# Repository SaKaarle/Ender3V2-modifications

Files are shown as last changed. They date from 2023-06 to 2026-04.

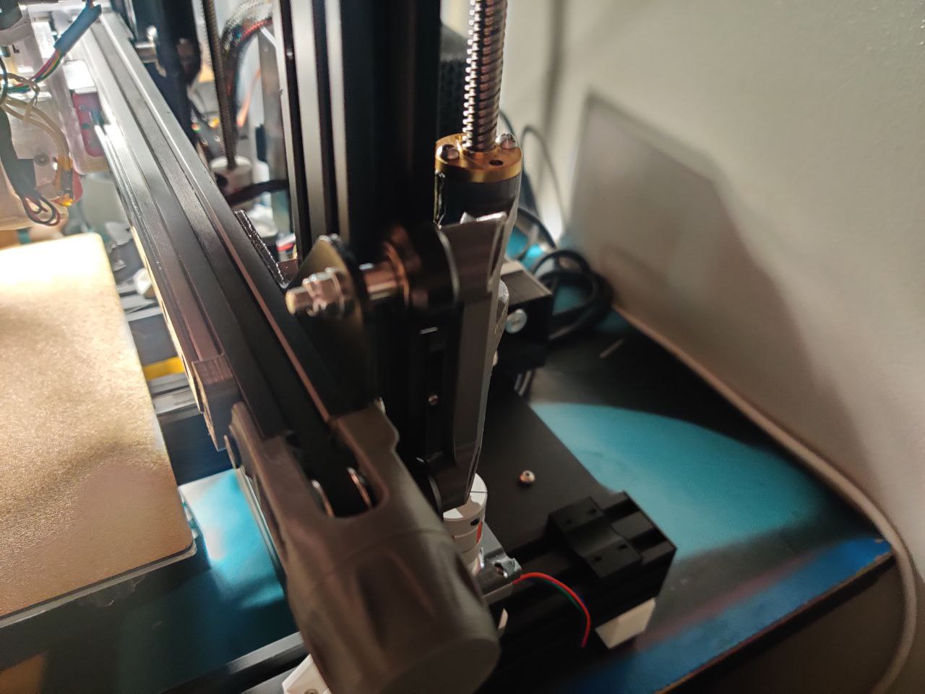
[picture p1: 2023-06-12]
pictures/photo1686598149(1).jpeg

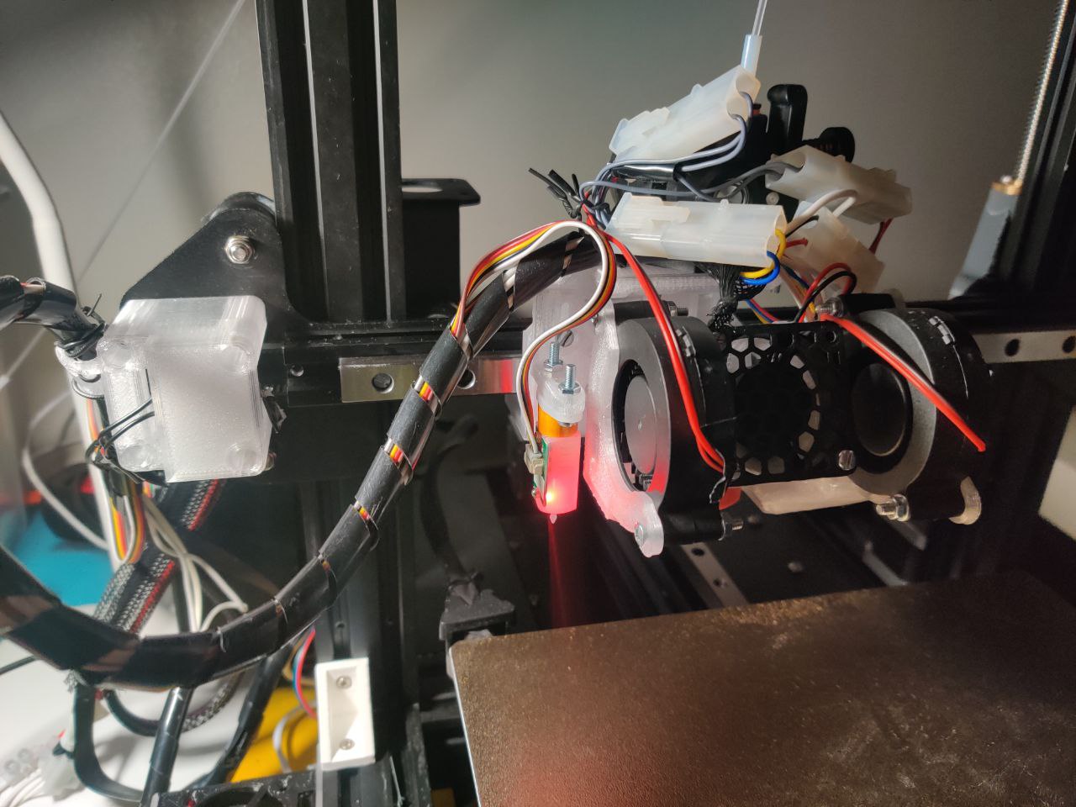
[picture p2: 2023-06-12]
pictures/photo1686598149(3).jpeg

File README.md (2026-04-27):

# Ender3V2-modifications
Mods of my Ender 3 V2 with .blend and .STL files
Also information.
  
## List:
- [What have I done](#what-else-what-have-i-done)
- [Required modding](#required-modding)
- [Filament spool / roll weights](#filament-spool--roll-weights)

## Backing up .blend files
This repo is made for me to publicly upload my mods and methods I used for creating my own modifications.
## Why and what?
Personal backup, and helping myself to remember what tools I used and what I have done to make my ENDER 3V2 personal without any CAD background.
I'm trying to be crystal clear, open and link any of my mods that I remixed or modified. Not trying to break any rules as great as possible.

## Blender? Really? NO PLEASE NO
### FreeCAD > Blender
  
Blender is good for simple mesh edits / remixes, but still. Wasting time on blender CAD Sketcher is not a good idea.
## What else? What have I done?

List of mods that are edited to my flavour.
- X-axis cover (Destroyed my M3 x 40mm screws. Had to create M3 x 30mm screw mod. Then I added limit switch mod for Linear Mod carriage)
- X-axis linear rail carriage.
- Dual Z-axis to fit washers and better support for Z-axis motor. Coupler was hitting the original part.
- Y-axis motor holder. Was hitting bed tensioner screws. It needs to be modded / replaced.
- Y-axis drilling helpper. Holes for MGN12 linear rail. It needs changes and I have to create mod that supports Y-axis belt better and make it more straight.
  
These are just top of my head what I remember, but I'll create better list of parts and mods.

## Required Modding
  
**X-axis:** It has had SOME mods and fixes. BLV set with [FrankEnstein](https://github.com/kevinakasam/FrankEnstein-Duct/tree/main) and modded base to fit screws and hold it together better on the X gantry / carriage.
X-axis only needs Motor holder / endswitch holder which would be better and for double shear support. Not necessary this last part but better than nothing.
  
**Y-axis:** Uses BLV base, but could use dual mgn rail system. Not sure if it's benefitting at all for acceleration results, but will see. Currently max y-axis acceleration is 5000, but I use 10000mm/s². Seams will show the high acceleration results.
Y-axis upgrade path is simple: Dual MGN rail. New bed heater system. New bed heater means = New PSU and silicon heater.
  
**Z-axis:** Dual leadscrew / BLV Z-axis. I could just use KevinAkaSam's Z-axis mod. Only needs printing the necessary parts.
Z-axis not necessarily needs upgrade, except the belted mod. 
  
**DUCT:** Yeah nothing really. FrankEnstein V2
  
**Extruder:** Orbiter V2.0 -> V2.5 upgrade done. Better quality? "yes". Worth it? I guess?
  
**Enclosure:** Needs filtering system
  
**Motherboard and Electronics:** GPIO pins, fans and new motherboard holder location and design. Led control from RPi 5 or from RPi Pico.
  
**Filament runout sensor:** Not installed

## Filament spool / roll weights
  
- CR-PETG or maybe other Creality Plastic roll weight: **190g**
- Fuj:tech Cardboard filament roll weight: **220g**
- Sunlu JAYO, old mass producted filament roll weight: **133g**

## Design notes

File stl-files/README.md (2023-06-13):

# STL files of mods

`rinkula.stl` file is for Y stopper switch to activate. Some moveable printable Y switch holder is fine and works. Literally made 2-3 wheels to act as "replacement" for POM Wheels that hit the Y switch.

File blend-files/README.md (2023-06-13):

# Backup of files
## Main Duct mod
[Main duct mod is huge. 100mb and it's like test enviroment](https://github.com/SaKaarle/Ender3V2-modifications/blob/main/blend-files/ModdedVersionDuct.7z)
It has my old mods, tests etc. Didn't cleaned it.

It also contains the X-axis carriage mod for linear rails. It's remixed to have:
- thicker bottom for strenght. needs changes for belts. Straightening the belt by adding height piece before the holes. Easier way i'd guess. If I really wanted to strenght to that piece, I'd add 3 long M3 - M4 to press on belts.
- added 2 nut holes for BLTouch. Prolly going to change it due to the center screwhole is behind left side fanduct.
- leftside stopper for better switch action. Original didn't hit well on the switch so I added more contact area
- 2 holes that are unnecessary. Should be removed.
- Hotend screwholes. Originals were "odd" shaped and I changed them to cylinderlike shape. This gives me chance to change from my Hero Me Gen -mod to Frankenstein-Duct easly for example.

## Duct With No Name
It's Minimev4 or minionD mod fused with hero me gen. HMG has great ducts IMO and I added a support for it. It can be printed without BMS Dragonfly adapter to support MK8 style hotend.
It has little cable management for Thermistor and heater cable.

No heatinsert? no. I mod and print a lot so obviously it would've been waste of brass. 

It's integrated with Orbiter V2.0 extruder and added small flex support. 2 holes for zipties for cable

Modular BLTouch support that needs changes

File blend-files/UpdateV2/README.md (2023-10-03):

Updated version:
Changes:
- Made changes to fanduct. Created "own" fan holes and lowered Orbiter extruder mount about 8mm downwards.
- Stronger (but flexing still on PET-G materials, not a surprise)
- Moved extruder holes 1mm towards front
- ADXL345 mount (not tested)
- BLTouch mount changes. Got annoying to change fans or what not. Made it more "easy" to access / mod. Not tested if it even fits or measured distance between BLTouch and nozzle.

Issues:
- Not tested
- Fan performance not tested. Model needs somekind of "duct" towards hotend.

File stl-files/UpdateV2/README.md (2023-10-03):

Updated STL files and blend files.

Performance? Unknown.

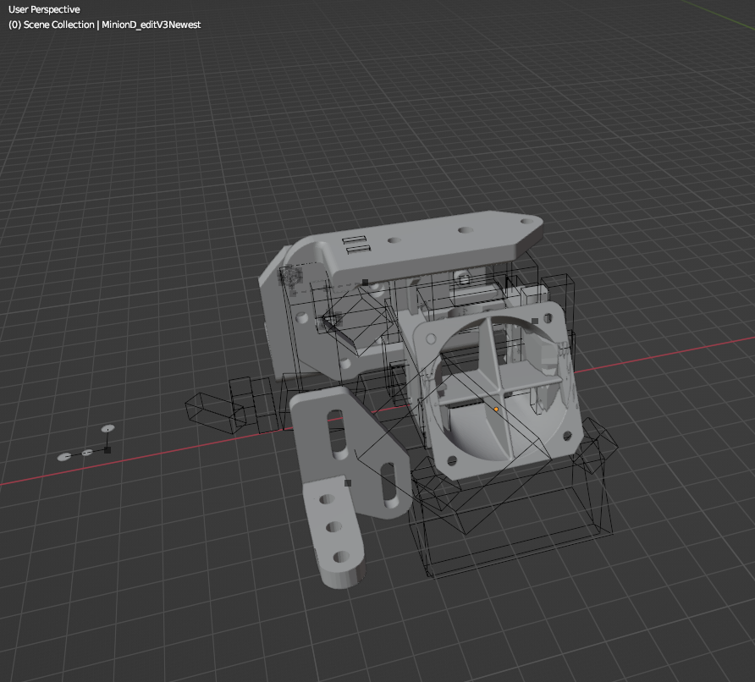
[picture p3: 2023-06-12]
pictures/GitHub ugly mod.PNG

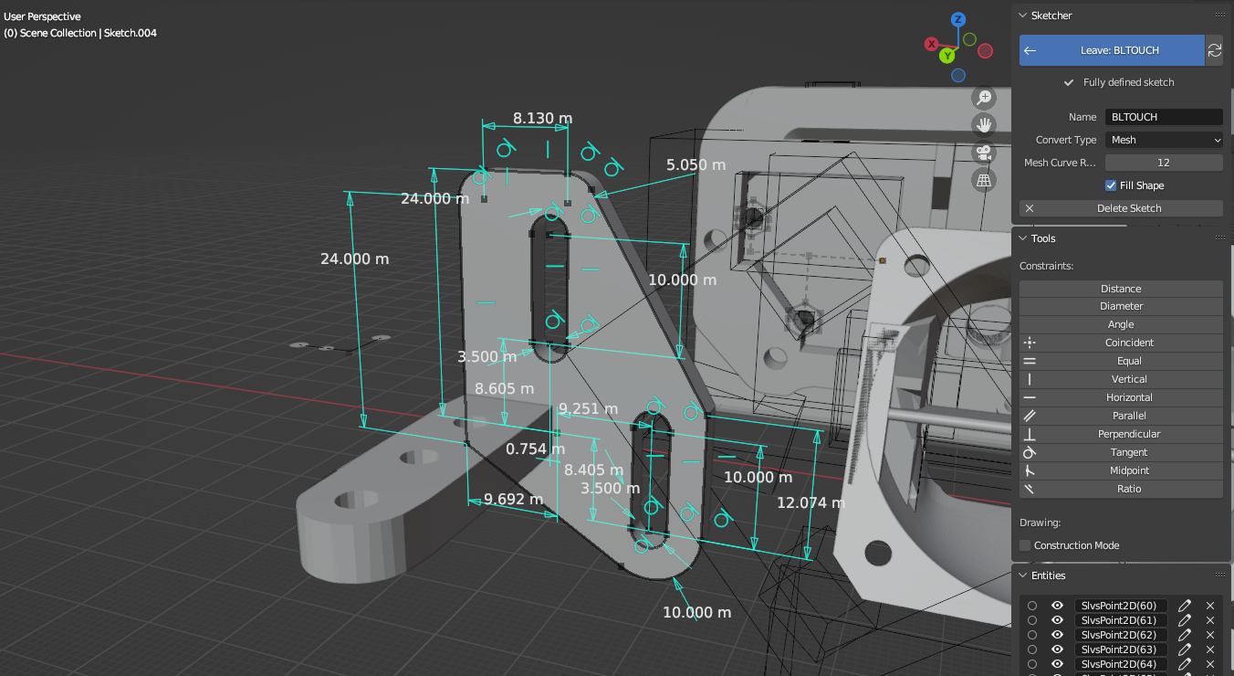
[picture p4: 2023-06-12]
pictures/GitHub_BLtouch.PNG

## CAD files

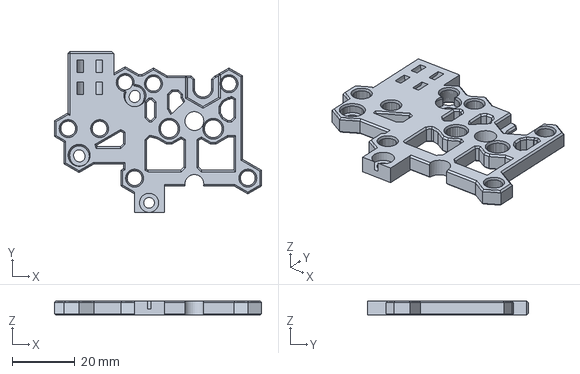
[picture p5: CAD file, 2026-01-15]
Mods/BasePlateEdit.FCStd
65.8 x 51.0 x 4.50 mm

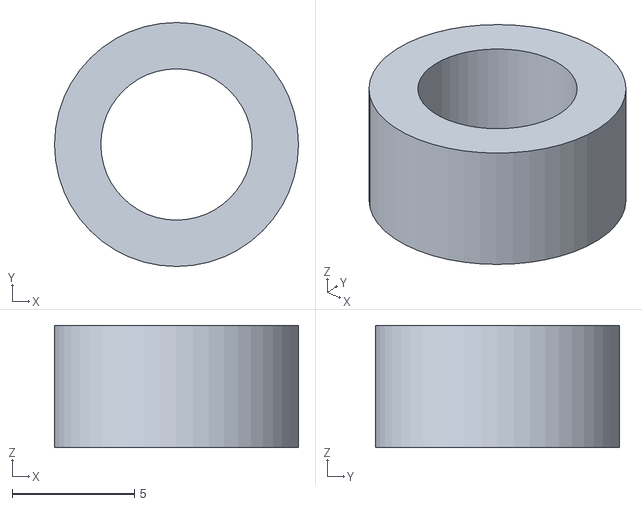
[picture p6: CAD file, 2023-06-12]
stl-files/BED Linear Mod Ender 3 v2-Rinkula.stl
10.0 x 10.0 x 5.00

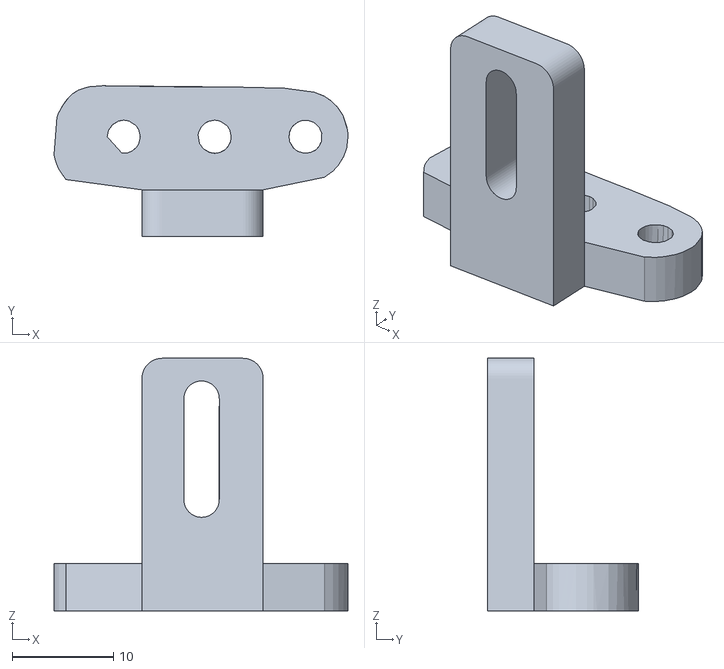
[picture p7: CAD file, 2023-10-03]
stl-files/UpdateV2/ModdedVersionDuct-BLTOUCH2.stl
29.1 x 14.9 x 25.0

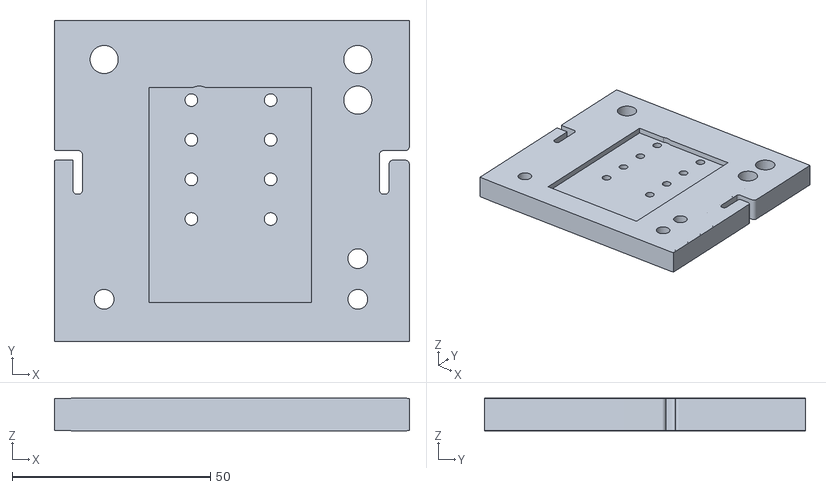
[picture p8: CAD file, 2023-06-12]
stl-files/BED Linear Mod Ender 3 v2-BED_Linear_Mod_Ender_3_v2-Creality-Ender3-V2-rev4_002.stl
89.6 x 81.0 x 8.20

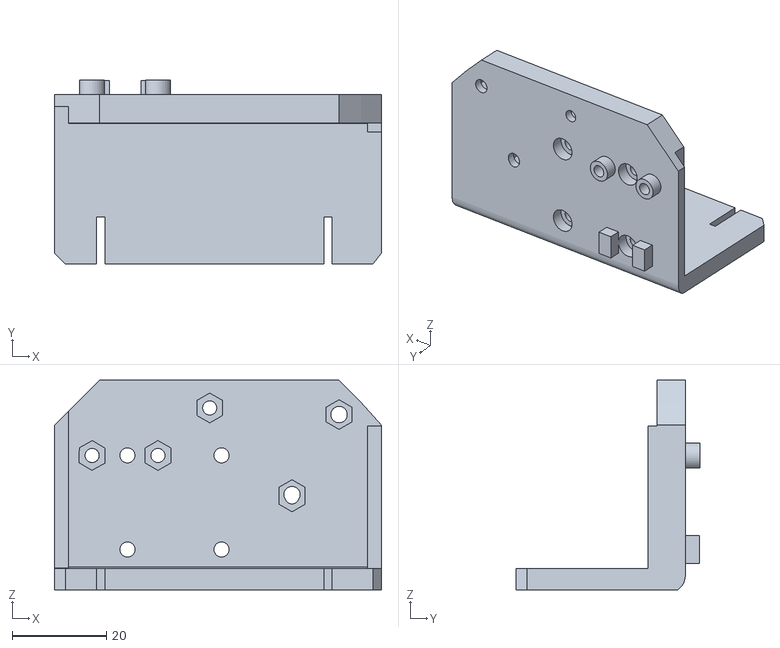
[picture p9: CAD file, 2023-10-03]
stl-files/UpdateV2/ModdedVersionDuct-Linear_rail_MGN12_x_axis_backplate_modded_V2.stl
69.5 x 39.1 x 44.6

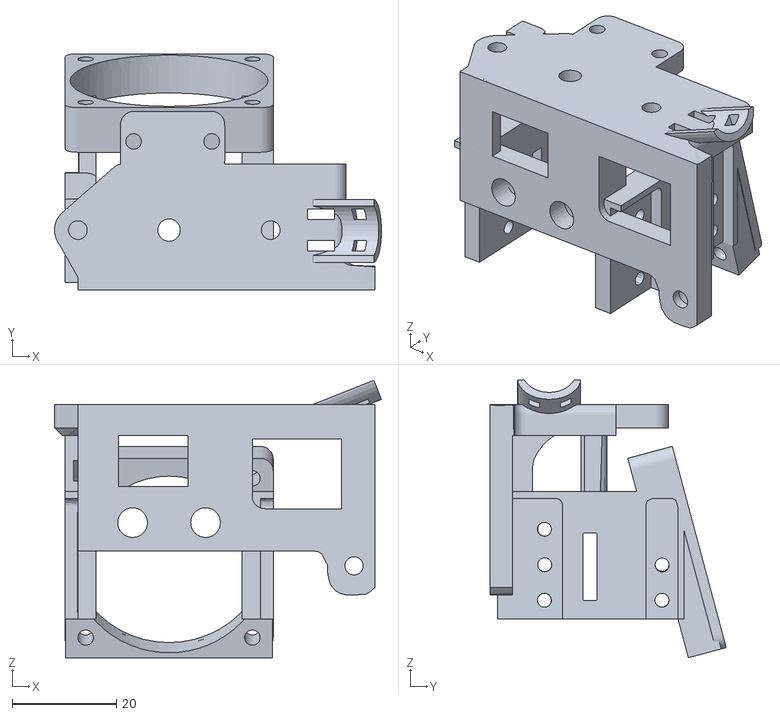
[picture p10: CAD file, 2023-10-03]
stl-files/UpdateV2/ModdedVersionDuct-FANShroud_003.stl
62.8 x 45.4 x 53.3

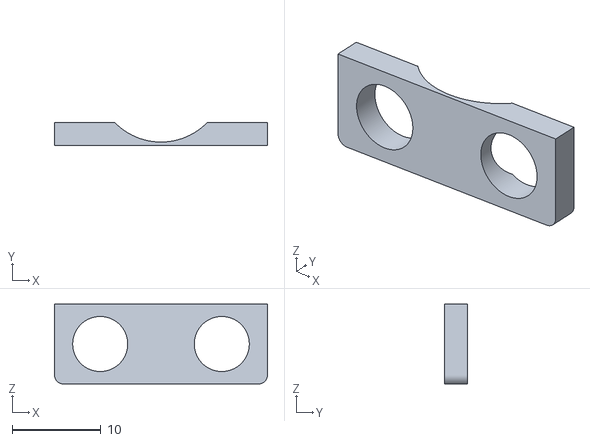
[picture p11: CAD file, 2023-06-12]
stl-files/ModdedVersionDuct-Dragon_Fly_Phaetus_Spacer_modded.stl
24.0 x 2.59 x 9.00

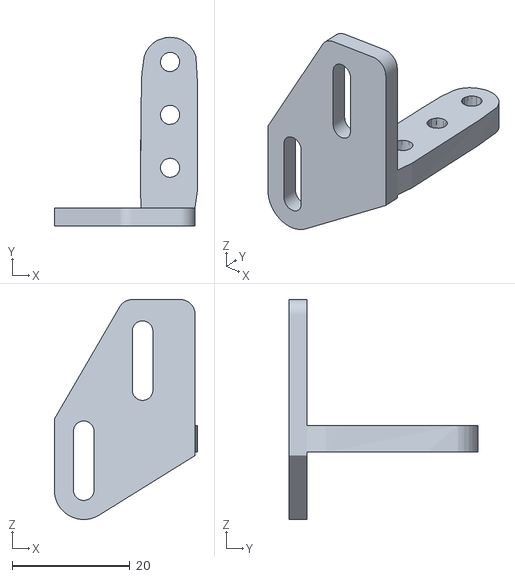
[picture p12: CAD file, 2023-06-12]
stl-files/ModdedVersionDuct-BLTOUCH.stl
24.4 x 32.1 x 37.4

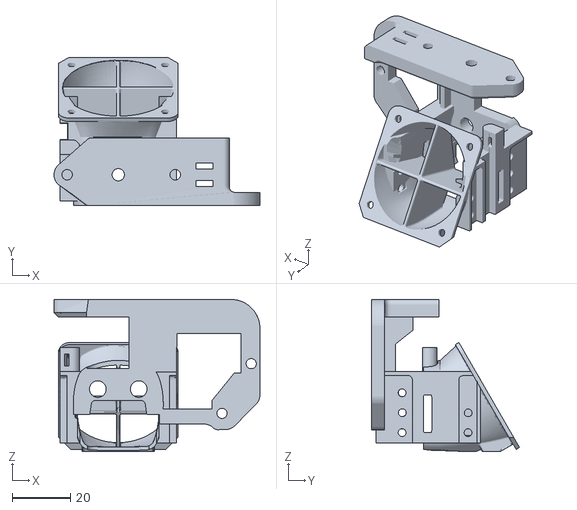
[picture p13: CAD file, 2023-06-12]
stl-files/ModdedVersionDuct-MinionD_editV3Newest.stl
70.5 x 50.7 x 52.1

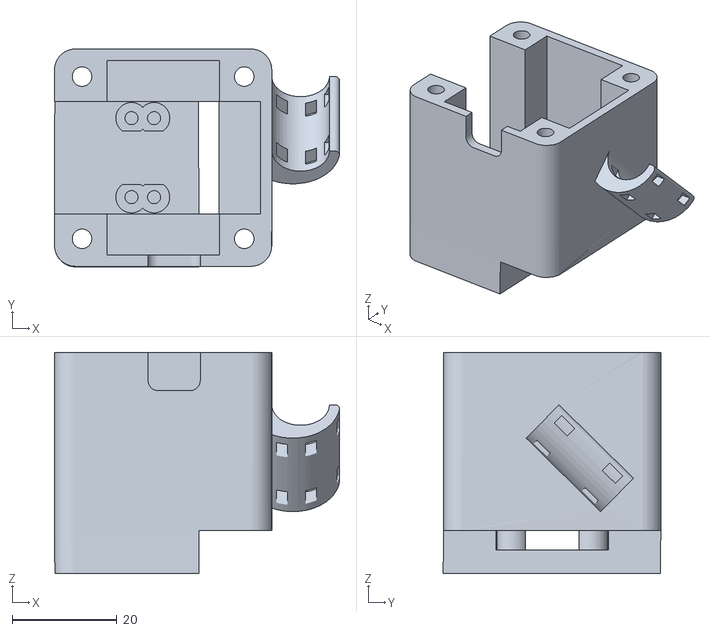
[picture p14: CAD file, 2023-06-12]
stl-files/X_AXIS_EDIT_m3x30mm_screws-x_axis_cover_cable_003.stl
54.5 x 41.6 x 42.3

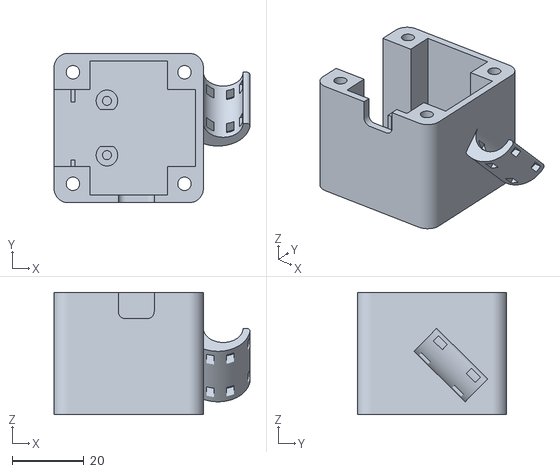
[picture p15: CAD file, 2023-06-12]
stl-files/X_AXIS_EDIT_m3x30mm_screws-x_axis_cover_cable_NonLinearRail.stl
54.5 x 41.5 x 34.0

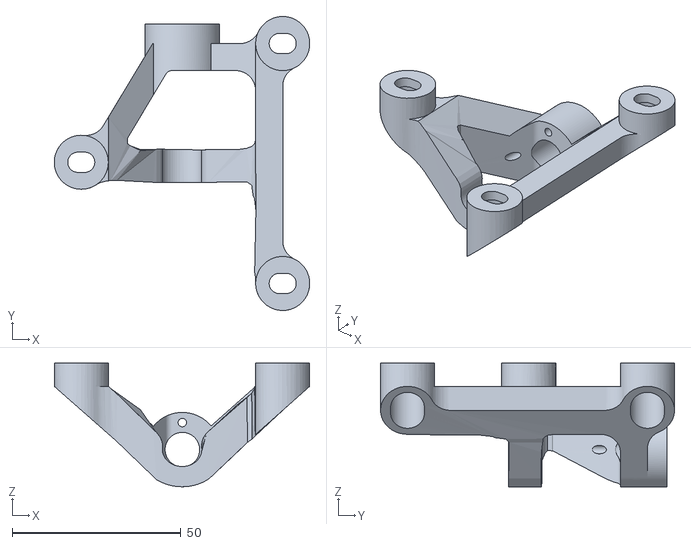
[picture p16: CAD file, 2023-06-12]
stl-files/ZaxisFix-Bracket_without_insertsSpaceWashers0_9mm_001.stl
75.6 x 87.0 x 36.6

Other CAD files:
Mods/BasePlateEdit-BodyHoleFinishedIguess.3mf
stl-files/ModdedVersionDuct-Linear_rail_MGN12_x_axis_backplate_modded_V3.stl
stl-files/ZaxisFix-Bracket_without_insertsSpaceWashers0_9mm.stl
blend-files/80mmSlimEdit.blend
blend-files/BED Linear Mod Ender 3 v2.blend
blend-files/BEDModel.blend
blend-files/BalikkaSpool.blend
blend-files/OrbiterEdit_v1.blend
blend-files/SpoolHolder V2.blend
blend-files/X_AXIS_EDIT_m3x30mm_screws.blend
blend-files/Y-axis Edit.blend
blend-files/ZaxisFix.blend
blend-files/ZaxisFix_V2.blend

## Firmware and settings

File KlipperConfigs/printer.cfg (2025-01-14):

# This file contains common pin mappings for the BIGTREETECH SKR mini
# E3 v3.0. To use this config, the firmware should be compiled for the
# STM32G0B1 with a "8KiB bootloader" and USB communication/USART.

# usb-Klipper_stm32g0b1xx_1300350015504B5735313920-if00


# The "make flash" command does not work on the SKR mini E3. Instead,
# after running "make", copy the generated "out/klipper.bin" file to a
# file named "firmware.bin" on an SD card and then restart the SKR
# mini E3 with that SD card.

# See docs/Config_Reference.md for a description of parameters.

### Calibrations:
# Flow Rate / Extrusion Multiplier
# 89 - 91
# 90.5 def
# 0.965 best?

# Cura Start End G-Codes
# START_PRINT BED_TEMP={material_bed_temperature_layer_0} EXTRUDER_TEMP={material_print_temperature_layer_0}
# END_PRINT

# https://www.klipper3d.org/G-Codes.html#print_stats

# Orca
# start_print BED_TEMP=[bed_temperature_initial_layer_single] EXTRUDER_TEMP=[nozzle_temperature_initial_layer]

### Important notes:
### - Hero Me Gen Fan Speed Max 75% PLA
### - 

## Client variable macro for your printer.cfg
[gcode_macro _CLIENT_VARIABLE]
variable_use_custom_pos   : True ; use custom park coordinates for x,y [True/False]
variable_custom_park_x    : 10.0   ; custom x position; value must be within your defined min and max of X
variable_custom_park_y    : 10.0   ; custom y position; value must be within your defined min and max of Y
variable_custom_park_dz   : 2.0   ; custom dz value; the value in mm to lift the nozzle when move to park position
variable_retract          : 1.0   ; the value to retract while PAUSE
variable_cancel_retract   : 5.0   ; the value to retract while CANCEL_PRINT
variable_speed_retract    : 35.0  ; retract speed in mm/s
variable_unretract        : 1.0   ; the value to unretract while RESUME
variable_speed_unretract  : 35.0  ; unretract speed in mm/s
variable_speed_hop        : 30.0  ; z move speed in mm/s
variable_speed_move       : 100.0 ; move speed in mm/s
variable_park_at_cancel   : True ; allow to move the toolhead to park while execute CANCEL_PRINT [True/False]
variable_park_at_cancel_x : 245.0  ; different park position during CANCEL_PRINT [None/Position as Float]; park_at_cancel must be True
variable_park_at_cancel_y : 234.0  ; different park position during CANCEL_PRINT [None/Position as Float]; park_at_cancel must be True
# !!! Caution [firmware_retraction] must be defined in the printer.cfg if you set use_fw_retract: True !!!
variable_use_fw_retract   : False ; use fw_retraction instead of the manual version [True/False]
variable_idle_timeout     : 0     ; time in sec until idle_timeout kicks in. Value 0 means that no value will be set or restored
gcode:


## includes:
[include mainsail.cfg]
[include fluidd.cfg]
[include KAMP_Settings.cfg]
#[include Adaptive_Mesh.cfg]
#[include Line_Purge.cfg]
[include Input_Shaper.cfg]
[include StepperConf.cfg]

[extruder]
max_extrude_only_distance: 500.0
max_extrude_only_velocity: 120.0
max_extrude_cross_section: 5
max_extrude_only_accel: 6000
step_pin: PB3
# != negative dir
dir_pin: PB4
enable_pin: !PD1
microsteps: 16 #128
full_steps_per_rotation: 200
rotation_distance: 4.586 #4.609 vakio: 4.637
nozzle_diameter: 0.400
filament_diameter: 1.750
pressure_advance: 0.04
pressure_advance_smooth_time: 0.03

# 110 + || - measured_value = length
# length / 100 * old_rotation_distance = new rotation distance
# 110 - 11 = 99 -> 99/100 = 0.99 -> 0.99 * 4,587 = 4.54113
# 26.11.2023 = 4.65
# 4.666
# 4.625
# 4,666 * 99,12 / 100


heater_pin: PC8
sensor_type: EPCOS 100K B57560G104F
sensor_pin: PA0
min_temp: 0
max_temp: 300
min_extrude_temp: 170

[tmc2209 extruder]
uart_pin: PC11
tx_pin: PC10
uart_address: 3
interpolate: true
# stealthchop_threshold: 0
run_current: 0.83 #** 0.85 max RMS amp. Good value 0.75
# hold_current: 0.100
sense_resistor: 0.11 #**
driver_TBL: 0
driver_HEND: 6
driver_HSTRT: 7
driver_TOFF: 4

[printer]
kinematics: cartesian
max_velocity: 400
max_accel: 10000
# 50mm^2  +  2 × 10000 mm/s2 × (0.5 ratio × 100mm) = 1002500 mm/s??? end_velocity^2
minimum_cruise_ratio: 0.5
#max_accel_to_decel: 5000 # <- #max_accel_to_decel:
#   A pseudo acceleration (in mm/s^2) controlling how fast the
#   toolhead may go from acceleration to deceleration. It is used to
#   reduce the top speed of short zig-zag moves (and thus reduce
#   printer vibration from these moves). The default is half of
#   max_accel.
square_corner_velocity: 5.0
max_z_velocity: 30 #15
max_z_accel: 500

[stepper_x]
step_pin: PB13
dir_pin: !PB12
enable_pin: !PB14
microsteps: 32 #128 tai 32 no interp
rotation_distance: 40
endstop_pin: ^PC0
position_endstop: -1
position_min: -1
position_max: 248
homing_speed: 80

[tmc2209 stepper_x]
uart_pin: PC11
tx_pin: PC10
uart_address: 0
run_current: 1.03
interpolate: False #False
stealthchop_threshold: 0

[stepper_y]
step_pin: PB10
dir_pin: PB2 # 48motor had "!PB2". 60mm has non. 
enable_pin: !PB11
microsteps: 32 #128 tai 32 no interp
rotation_distance: 40
endstop_pin: ^PC1
#-12
position_endstop: -15
#-12
position_min: -15
position_max: 237
homing_speed: 80

[tmc2209 stepper_y]
uart_pin: PC11
tx_pin: PC10
uart_address: 2
run_current: 0.98 #Old 0.96. 1.03 vois olla liian kuuma. 1.4 laskemalla...
interpolate: False #False
stealthchop_threshold: 0

[stepper_z]
step_pin: PB0
dir_pin: PC5
enable_pin: !PB1
microsteps: 32 #128
rotation_distance: 8
# endstop_pin: ^PC2
# position_endstop: 0.0
endstop_pin: probe:z_virtual_endstop
position_min: -5
position_max: 250

[tmc2209 stepper_z]
uart_pin: PC11
tx_pin: PC10
uart_address: 1
run_current: 1.05 #1.6 or 1.58. Dual Z axis motors.
interpolate: False #False
stealthchop_threshold: 0


[heater_bed]
heater_pin: PC9
sensor_type: EPCOS 100K B57560G104F
sensor_pin: PC4
min_temp: 0
max_temp: 130

[heater_fan hotend_fan]
pin: PB15
heater: extruder
heater_temp: 45.0
fan_speed: 0.97
#   The fan speed (expressed as a value from 0.0 to 1.0) that the fan
#   will be set to when its associated heater is enabled. The default
#   is 1.0

[controller_fan electronic_enclosure_fan]
pin: PC7
idle_timeout: 60

[fan]
pin: PC6

[mcu]
serial: /dev/serial/by-id/usb-Klipper_stm32g0b1xx_1300350015504B5735313920-if00
# serial: /dev/ttyAMA0
# restart_method: command

[board_pins]
aliases:
    # EXP1 header
    EXP1_1=PB5,  EXP1_3=PA9,   EXP1_5=PA10, EXP1_7=PB8, EXP1_9=<GND>,
    EXP1_2=PA15, EXP1_4=<RST>, EXP1_6=PB9,  EXP1_8=PD6, EXP1_10=<5V>

[mcu rpi]
serial: /tmp/klipper_host_mcu

[adxl345]
cs_pin: rpi:None

[resonance_tester]
accel_chip: adxl345
probe_points:
    117.5, 117.5, 30  # an example

[bltouch]
sensor_pin: ^PC14
control_pin: PA1
##Oma modi BLTouch = 43.8 - 4.5 = 39.3
## 10.2 - 9.81 = 0.39
x_offset: -52.0 #50
y_offset: -3.0 #5
#z_offset = 1.625
#z_offset: -1.225

#[output_pin beeper]
#pin: PB5

[safe_z_home]
home_xy_position:169.5,120.5
# Change coordinates to the center of your print bed

z_hop:7
z_hop_speed:30
speed:300
# Move up 10mm z_hop_speed: 5


[bed_mesh]

##Laskettu arvo 0,0 -> 39.15,39.15 -> ProbePoint 0,0 -> 78.4,39.15 -> 0,1 -> 156.6,39.15 -> 0,2
## X = (bltouch_x)43.8 + (bed_point_y)39.15 = 82.95
## Y = (bltouch_y)10.2 + (bed_point_y)39.15 = 49.35
## 195.75

speed:300
horizontal_move_z:7
mesh_min:47.5,47.5
mesh_max:188.5,188.5
probe_count:5,5
algorithm:lagrange
fade_start:1
fade_end:10
fade_target:0

[gcode_macro probe_calibration]
gcode: PROBE_CALIBRATE

[gcode_macro screws_tilt_adjust]
gcode: SCREWS_TILT_CALCULATE

[screws_tilt_adjust]
## 35 + 43.8
## 35 + 10.2
## 235 - 43.8
## 235 - 10.2
screw1:102,53
screw1_name:front left screw
screw2:237,53
screw2_name:front right screw
screw3:237,188
screw3_name: rear right screw
screw4:102,188
screw4_name: rear left screw
horizontal_move_z: 10
speed: 300
screw_thread: CW-M4

# screw1:70.5,37.5
# screw1_name:front left screw
# screw2:225,37.5
# screw2_name:front right screw
# screw3:225,207.5
# screw3_name: rear right screw
# screw4: 70.5,207.5
# screw4_name: rear left screw
# horizontal_move_z: 10
# speed: 50
# screw_thread: CW-M4

#====================================================================

# TEMPERATUR SENSORS

#====================================================================

[temperature_sensor rpi_temp]
sensor_type: temperature_host
sensor_path: /sys/class/thermal/thermal_zone0/temp
#   The path to temperature system file. The default is
#   "/sys/class/thermal/thermal_zone0/temp" which is the temperature
#   system file on a Raspberry Pi computer.

[temperature_sensor raspberry_pi]

sensor_type: temperature_host
min_temp: 10
max_temp: 100

[temperature_sensor Board Temp]

sensor_type: temperature_mcu
min_temp: 0
max_temp: 100

[virtual_sdcard]
path: /home/pi/printer_data/gcodes

# Enable object exclusion
[exclude_object]
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

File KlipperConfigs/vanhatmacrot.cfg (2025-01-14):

[gcode_macro START_PRINT]
gcode:
    {% set BED_TEMP = params.BED_TEMP|default(60)|float %}
    {% set EXTRUDER_TEMP = params.EXTRUDER_TEMP|default(190)|float %}
    # Start bed heating
    M140 S{BED_TEMP}
    # Use absolute coordinates
    G90
    # Reset the G-Code Z offset (adjust Z offset if needed)
    SET_GCODE_OFFSET Z=0.0
    # Home the printer
    G28
    #BED_MESH_CALIBRATE
    G29
    #BED_MESH_PROFILE LOAD=default

    G1 Z5 F3000
    # Move the nozzle very close to the bed
    # ??????????????????? G1 Z0.15 F300
    # Wait for bed to reach temperature
    M190 S{BED_TEMP}
    # Set and wait for nozzle to reach temperature
    M109 S{EXTRUDER_TEMP}
    #RESPOND MSG="Yeet"

    G1 Y0 ; 
    LINE_PURGE ; purge macro

    # Reset Extruder
    # G92 E0
    # # Move Z Axis up
    # G1 Z2.0 F3000
    # # Move to start position
    # G1 X2.1 Y20 Z0.28 F5000.0
    # # Draw the first line
    # G1 X2.1 Y200.0 Z0.28 F1500.0 E15
    # # Move to side a little
    # G1 X2.4 Y200.0 Z0.28 F5000.0
    # # Draw the second line
    # G1 X2.4 Y20 Z0.28 F1500.0 E30
    # # Reset Extruder
    # G92 E0
    # # Move Z Axis up
    # G1 Z2.0 F3000

# gcode:
#     G28
#     BED_MESH_CALIBRATE
#     G0 X0 Y0 Z10 F6000
#     BED_MESH_PROFILE save=default
#     SAVE_CONFIG
#[gcode_macro G28]
#gcode: home

#region old macros

# [gcode_macro PAUSE]
# description: Pause the actual running print
# rename_existing: PAUSE_BASE
# # change this if you need more or less extrusion
# variable_extrude: 1.0
# gcode:
#   ##### read E from pause macro #####
#   {% set E = printer["gcode_macro PAUSE"].extrude|float %}
#   ##### set park positon for x and y #####
#   # default is your max posion from your printer.cfg
#   {% set x_park = printer.toolhead.axis_maximum.x|float - 5.0 %}
#   {% set y_park = printer.toolhead.axis_maximum.y|float - 15.0 %}
#   ##### calculate save lift position #####
#   {% set max_z = printer.toolhead.axis_maximum.z|float %}
#   {% set act_z = printer.toolhead.position.z|float %}
#   {% if act_z < (max_z - 2.0) %}
#       {% set z_safe = 2.0 %}
#   {% else %}
#       {% set z_safe = max_z - act_z %}
#   {% endif %}
#   ##### end of definitions #####
#   PAUSE_BASE
#   G91
#   {% if printer.extruder.can_extrude|lower == 'true' %}
#     G1 E-{E} F2100
#   {% else %}
#     {action_respond_info("Extruder not hot enough")}
#   {% endif %}
#   {% if "xyz" in printer.toolhead.homed_axes %}
#     G1 Z{z_safe} F900
#     G90
#     G1 X{x_park} Y{y_park} F6000
#   {% else %}
#     {action_respond_info("Printer not homed")}
#   {% endif %} 
#========================================
#OMA VANHA START PRINT
#========================================

# [gcode_macro START_PRINT]
# gcode:
#     {% set BED_TEMP = params.BED_TEMP|default(60)|float %}
#     {% set EXTRUDER_TEMP = params.EXTRUDER_TEMP|default(190)|float %}
#     # Start bed heating
#     M140 S{BED_TEMP}
#     # Use absolute coordinates
#     G90
#     # Reset the G-Code Z offset (adjust Z offset if needed)
#     SET_GCODE_OFFSET Z=0.0
#     # Home the printer
#     G28
#     #BED_MESH_CALIBRATE
#     G29
#     #BED_MESH_PROFILE LOAD=default
    
#     # Move the nozzle near the bed
#     G1 Z5 F3000
#     # Move the nozzle very close to the bed
#     G1 Z0.15 F300
#     # Wait for bed to reach temperature
#     M190 S{BED_TEMP}
#     BED_MESH_PROFILE LOAD=default
    
#     # Set and wait for nozzle to reach temperature
#     M109 S{EXTRUDER_TEMP}

#     #G1 Z2.0 F3000 ; Move Z Axis up little to prevent scratching of Heat Bed
#     G1 X0.1 Y20 Z0.3 F5000.0 ; Move to start position
#     G1 X0.1 Y200.0 Z0.3 F1500.0 E15 ; Draw the first line
#     G1 X0.4 Y200.0 Z0.3 F5000.0 ; Move to side a little
#     G1 X0.4 Y20 Z0.3 F1500.0 E30 ; Draw the second line
#     G92 E0 ; Reset Extruder
#     G1 Z2.0 F3000 ; Move Z Axis up little to prevent scratching of Heat Bed
#     G1 X5 Y20 Z0.3 F5000.0 ; Move over to prevent blob squish
    
#     # # Move to start for purge line
#     # G1 X0.1 Y20 Z0.3 F5000.0
#     # # Draw 1st line
#     # G1 X0.1 Y150.0 Z0.3 F1500.0 E15
#     # # Move to side a little
#     # G1 X0.4 Y150.0 Z0.3 F5000.0
#     # # Draw 2nd line
#     # G1 X0.4 Y20 Z0.3 F1500.0 E30
#     # # Reset extruder
#     # G92 E0
#     # # Move Z up a little
#     # G1 Z5.0 F3000

#=========================================================
#Vanha End Print
#=========================================================

# [gcode_macro END_PRINT]
# gcode:
#     # # Turn off bed, extruder, and fan
#     # M140 S0
#     # M104 S0
#     # M106 S0
#     # # Move nozzle away from print while retracting
#     # G91
#     # G1 X-2 Y-2 E-3 F300
#     # # Raise nozzle by 10mm
#     # G1 Z10 F3000
#     # G90
#     # # Disable steppers
#     # M84

#     G91 ;Relative positioning
#     G1 E-2 F2700 ;Retract a bit
#     G1 E-2 Z0.2 F2400 ;Retract and raise Z
#     G1 X5 Y5 F3000 ;Wipe out
#     G1 Z10 ;Raise Z more
#     G90 ;Absolute positioning

#     #G1 X0 Y{machine_depth} ;Present print
#     M106 S0 ;Turn-off fan
#     M104 S0 ;Turn-off hotend
#     M140 S0 ;Turn-off bed

#     M84 X Y E ;Disable all steppers but Z

# [gcode_macro RESUME]
# description: Resume the actual running print
# rename_existing: RESUME_BASE
# gcode:
#   ##### read E from pause macro #####
#   {% set E = printer["gcode_macro PAUSE"].extrude|float %}
#   #### get VELOCITY parameter if specified ####
#   {% if 'VELOCITY' in params|upper %}
#     {% set get_params = ('VELOCITY=' + params.VELOCITY)  %}
#   {%else %}
#     {% set get_params = "" %}
#   {% endif %}
#   ##### end of definitions #####
#   {% if printer.extruder.can_extrude|lower == 'true' %}
#     G91
#     G1 E{E} F2100
#   {% else %}
#     {action_respond_info("Extruder not hot enough")}
#   {% endif %}  
#   RESUME_BASE {get_params}


# [gcode_macro CANCEL_PRINT]
# description: Cancel the actual running print
# rename_existing: CANCEL_PRINT_BASE
# gcode:
#   TURN_OFF_HEATERS
#   CANCEL_PRINT_BASE
#   G1 Z10 ;Raise Z more
#   G90 ;Absolute positioning

#   #G1 X0 Y{machine_depth} ;Present print
#   #M106 S0 ;Turn-off fan
#   #M104 S0 ;Turn-off hotend
#   #M140 S0 ;Turn-off bed

#   M84 X Y E ;Disable all steppers but Z

#endregion

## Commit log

2023-06-12 Duct Mod
2023-10-03 Update
    Version 2. Improved bit
    [ModdedVersionDuct-BLTOUCH2.stl, ModdedVersionDuct-FANShroud_003.stl, ModdedVersionDuct-Linear_rail_MGN12_x_axis_backplate_modded_V2.stl]
